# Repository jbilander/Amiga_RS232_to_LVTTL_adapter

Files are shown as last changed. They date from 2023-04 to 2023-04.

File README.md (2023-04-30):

# Amiga RS232 to LVTTL adapter

Amiga RS232 to LVTTL with 3.3V Power converted and taken directly from the DB25 serial port 12V-pin (pin 9)

***
VERIFIED WORKING!!!<br />
https://drive.google.com/file/d/105Ov4MyicygtOqv-1FFOkmMn0a-dk8-Z/view?usp=sharing
***

Revision 1A
<br />
<a href="images/RS232_to_LVTTL_rev1a_pic1.png">
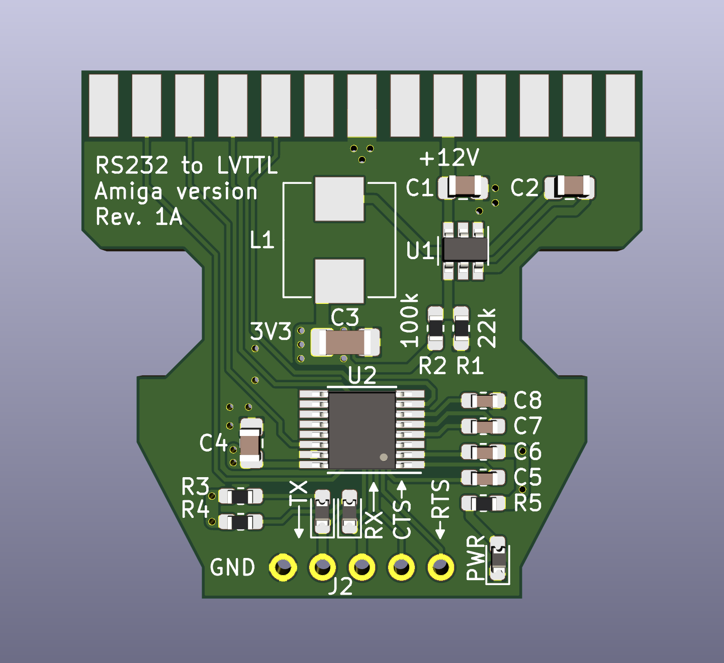
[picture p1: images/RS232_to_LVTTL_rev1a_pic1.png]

</a>
<a href="images/RS232_to_LVTTL_rev1a_pic2.png">
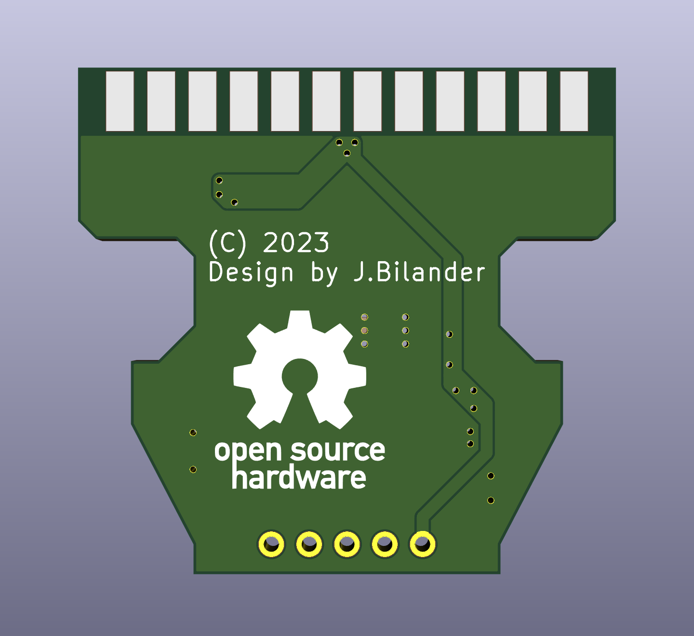
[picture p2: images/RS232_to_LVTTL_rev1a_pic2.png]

</a>
<br />
<a href="images/RS232_to_LVTTL_rev1a_pic3.png">
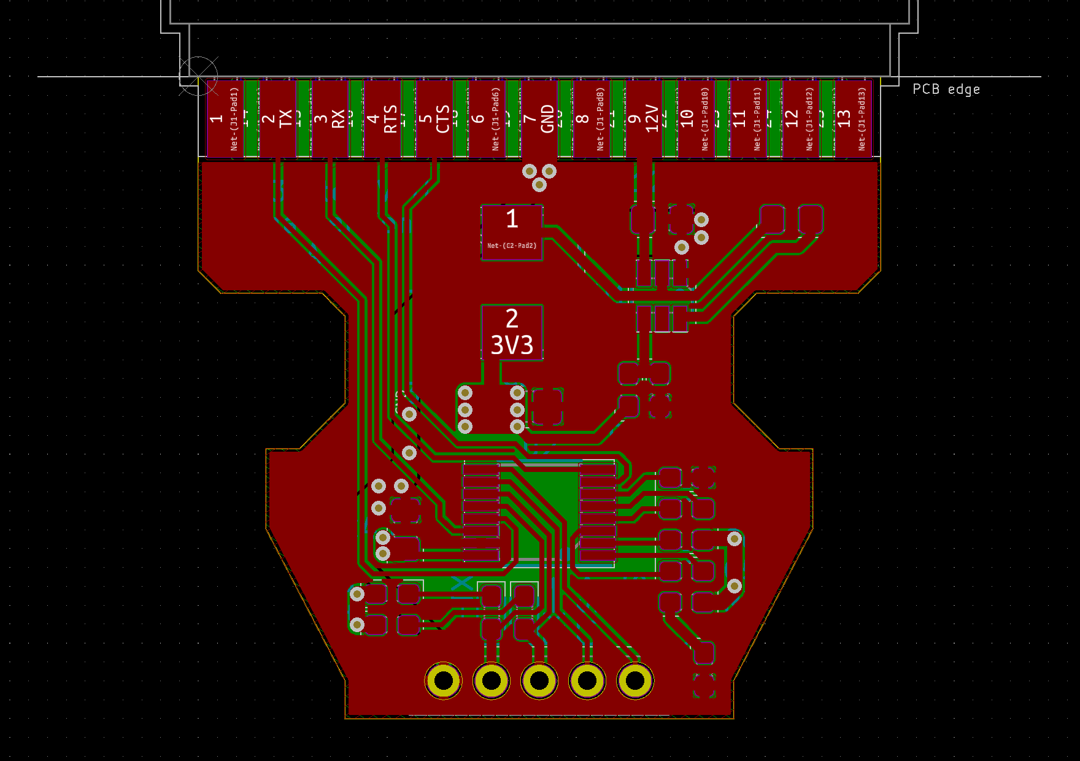
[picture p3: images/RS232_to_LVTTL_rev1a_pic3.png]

</a>
<br />
<a href="images/RS232_to_LVTTL_rev1a_pic4.jpg">
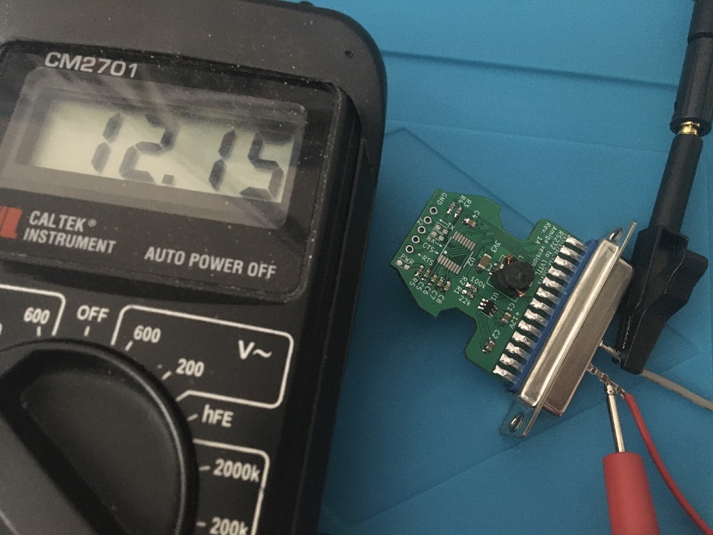
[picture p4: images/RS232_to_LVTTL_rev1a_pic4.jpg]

</a>
<a href="images/RS232_to_LVTTL_rev1a_pic5.jpg">
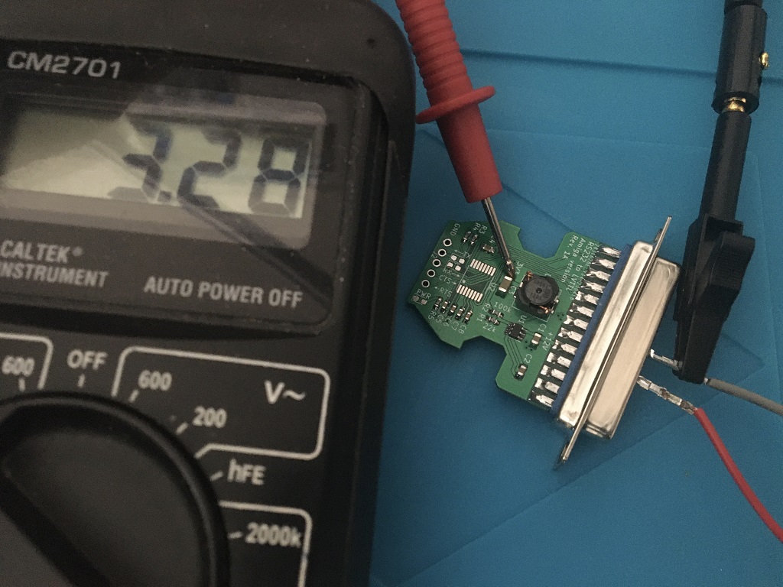
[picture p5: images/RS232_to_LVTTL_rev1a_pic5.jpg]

</a>
<br />
<a href="images/RS232_to_LVTTL_rev1a_pic6.jpg">
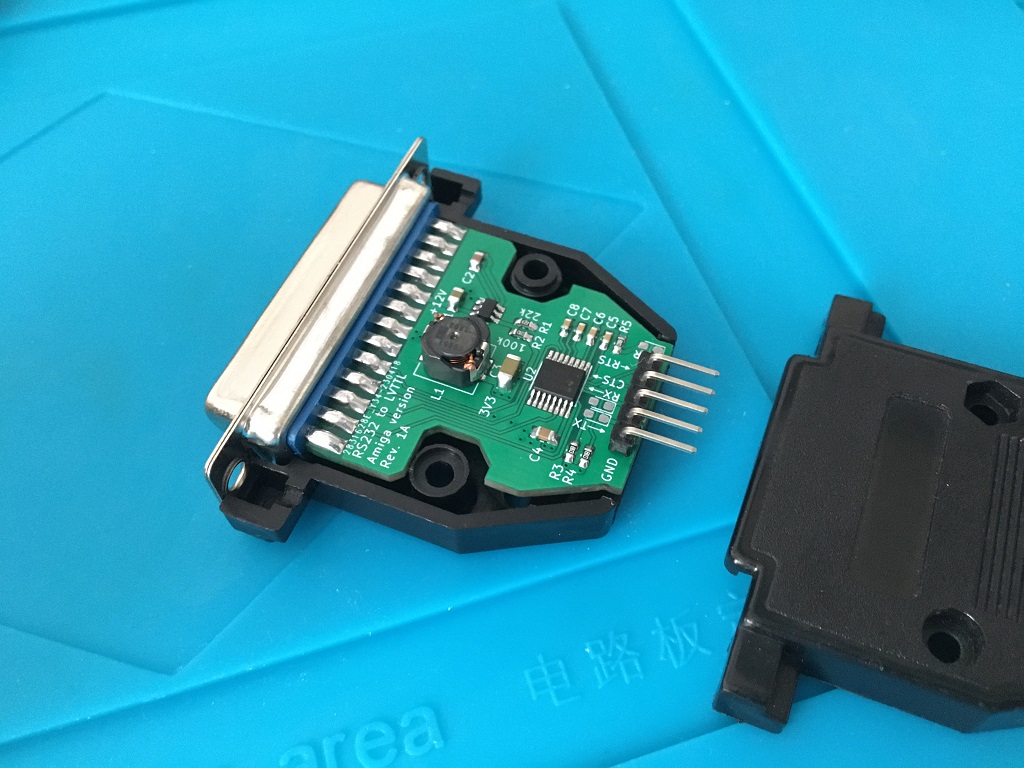
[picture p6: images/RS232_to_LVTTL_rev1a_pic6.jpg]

</a>

BOM Rev. 1A
---------
Designator  | Name/Value   | Package | Notes
-|-|-|-|
U1 | TPS54308 Step-down converter | SOT-23-6 | [TPS54308DDCR](https://www.mouser.com/ProductDetail/595-TPS54308DDCR)
U2 | MAX3232 RS-232 Interface IC 3-5.5V | TSSOP-16 | [MAX3232IPWR](https://www.mouser.com/ProductDetail/595-MAX3232IPWR)
L1 | CLF7045NIT-100M-D Power Inductor, 10 uH | 7 mm x 7 mm, height 4.5 mm | [CLF7045NIT](https://www.mouser.com/ProductDetail/810-CLF7045NIT100MD)
J1 | D-Sub DB25 Female connector | EdgeMount, serial port connector solder type | [D-Sub DB25F](https://www.aliexpress.com/item/32885764031.html)
J2 | 1x05 Right-Angle Single Row Male Pin Header | Type/Color: Reverse | [PinHeader](https://www.aliexpress.com/item/32892547934.html)
R1 | Feedback Resistor 22k Ω | 0603 | [RC0603FR-0722KL](https://www.mouser.com/ProductDetail/603-RC0603FR-0722KL)
R2 | Feedback Resistor 100k Ω | 0603 | [RC0603FR-07100KL](https://www.mouser.com/ProductDetail/603-RC0603FR-07100KL) 
R3-R5 | LED Resistor 1k Ω | 0603 | [RC0603FR-071KL](https://www.mouser.com/ProductDetail/603-RC0603FR-071KL)
C1 | Capacitor 10uF | 0805 | [TMK212BBJ106KG-T](https://www.mouser.com/ProductDetail/963-TMK212BBJ106KG-T)
C2,C4 | Capacitor 0.1uF = 100nF | 0805 |
C3 | Capacitor 47uF | 1206 | [EMK316BBJ476ML-T](https://www.mouser.com/ProductDetail/963-EMK316BBJ476ML-T)
C5-C8 | Capacitor 0.1uF = 100nF | 0603 | [CL10B104KO8NNWC](https://www.mouser.com/ProductDetail/187-CL10B104KO8NNWC)
D1-D3 | SMD LED | 0603 | [SMD LED 0603](https://www.aliexpress.com/item/1005003836509392.html)

***

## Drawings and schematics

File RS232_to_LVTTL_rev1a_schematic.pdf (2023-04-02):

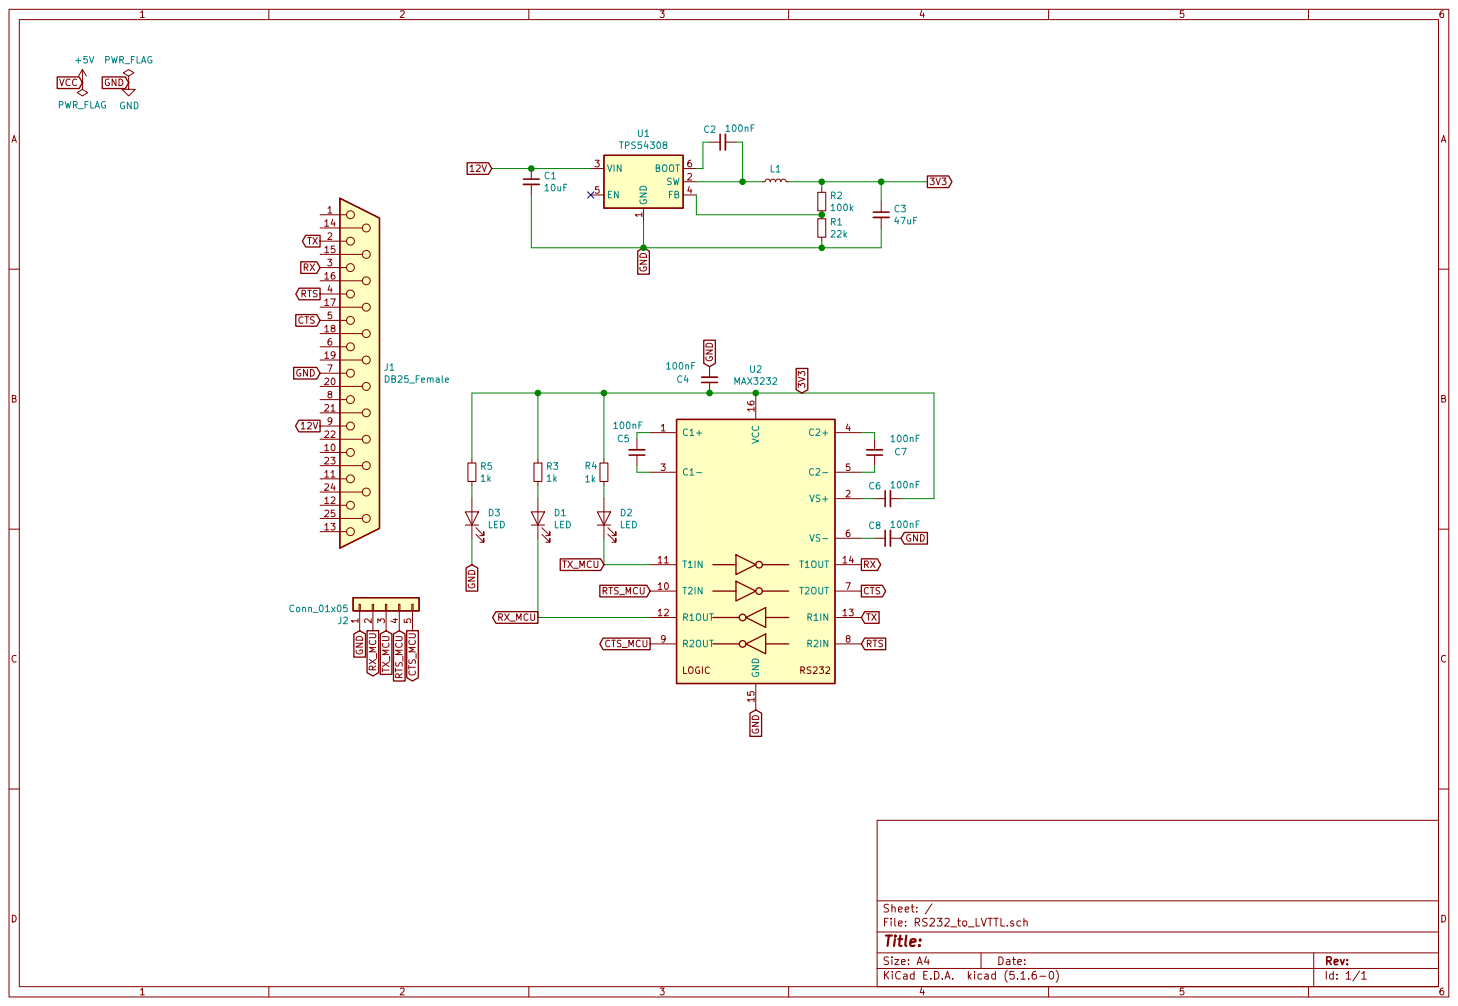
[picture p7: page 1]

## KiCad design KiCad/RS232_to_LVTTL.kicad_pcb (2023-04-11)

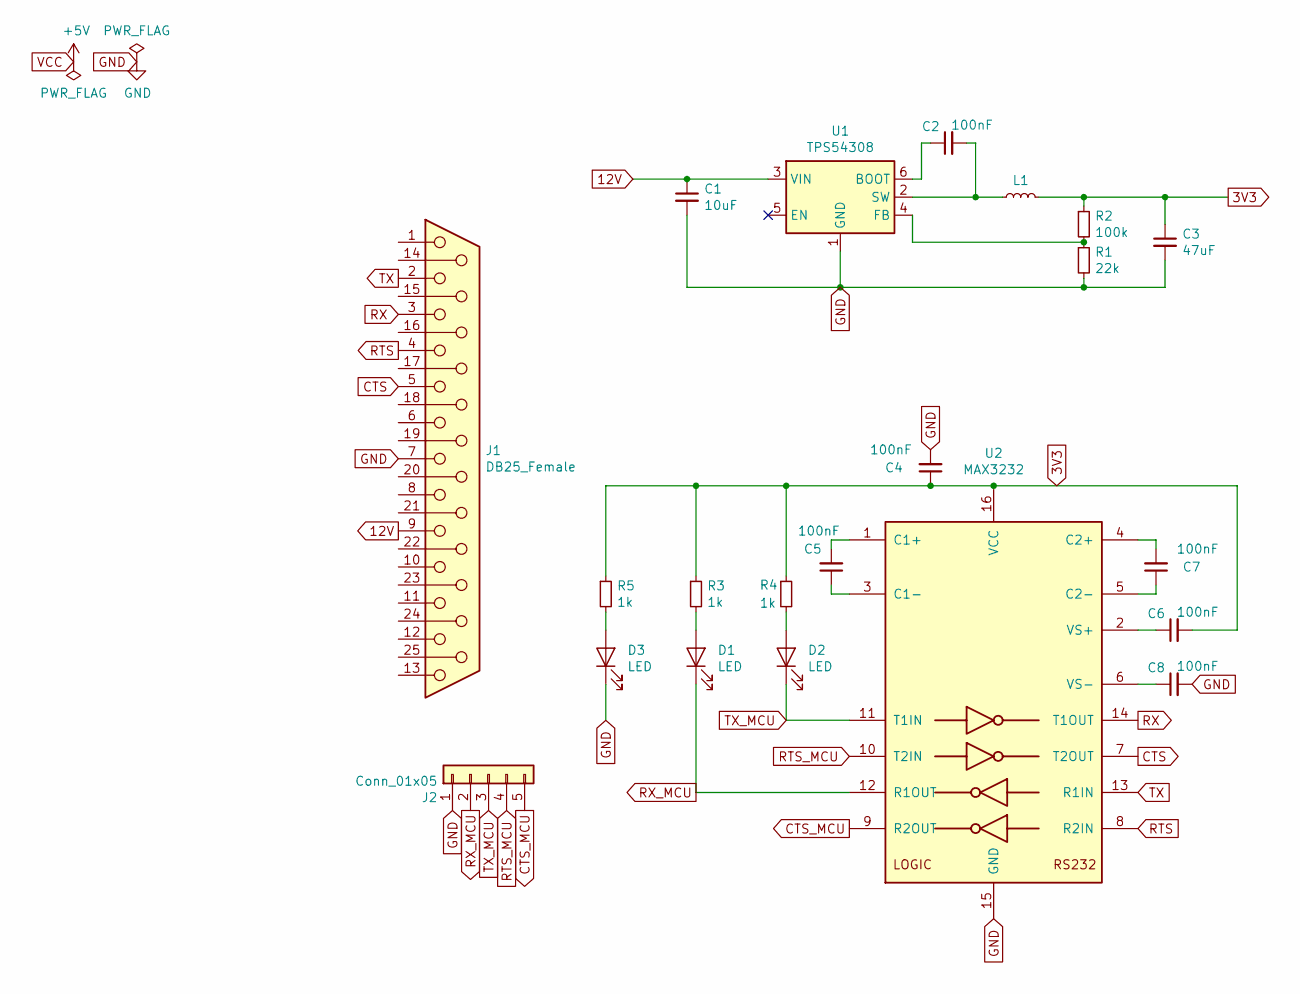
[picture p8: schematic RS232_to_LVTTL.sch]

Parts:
C1: 10uF; C_0805_2012Metric_Pad1.15x1.40mm_HandSolder
C2, C4: 100nF; C_0805_2012Metric_Pad1.15x1.40mm_HandSolder
C3: 47uF; C_1206_3216Metric_Pad1.42x1.75mm_HandSolder
C5, C6, C7, C8: 100nF; C_0603_1608Metric_Pad1.05x0.95mm_HandSolder
D1, D2, D3: LED; D_0603_1608Metric_Pad1.05x0.95mm_HandSolder
J1: DB25_Female; DSUB-25_Female_EdgeMount_P2.77mm
J2: Conn_01x05; PinHeader_1x05_P2.54mm_Vertical
L1: L_Small; L_Wuerth_HCM-7050
R1: 22k; R_0603_1608Metric_Pad1.05x0.95mm_HandSolder
R2: 100k; R_0603_1608Metric_Pad1.05x0.95mm_HandSolder
R3, R4, R5: 1k; R_0603_1608Metric_Pad1.05x0.95mm_HandSolder
U1: TPS54308; SOT-23-6
U2: MAX3232; TSSOP-16_4.4x5mm_P0.65mm

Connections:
3V3: C3.1, C4.1, C6.2, L1.2, R2.1, R3.1, R4.1, R5.1, U2.16 (VCC)
12V: C1.1, J1.9, U1.3 (VIN)
CTS: J1.5, U2.7 (T2OUT)
CTS_MCU: J2.5, U2.9 (R2OUT)
GND: C1.2, C3.2, C4.2, C8.2, D3.1 (K), J1.7, J2.1, R1.2, U1.1 (GND), U2.15 (GND)
unnamed: C2.1, U1.6 (BOOT)
unnamed: C2.2, L1.1, U1.2 (SW)
unnamed: C5.1, U2.3 (C1-)
unnamed: C5.2, U2.1 (C1+)
unnamed: C6.1, U2.2 (VS+)
unnamed: C7.1, U2.5 (C2-)
unnamed: C7.2, U2.4 (C2+)
unnamed: C8.1, U2.6 (VS-)
unnamed: D1.2 (A), R3.2
unnamed: D2.2 (A), R4.2
unnamed: D3.2 (A), R5.2
unnamed: R1.1, R2.2, U1.4 (FB)
RTS: J1.4, U2.8 (R2IN)
RTS_MCU: J2.4, U2.10 (T2IN)
RX: J1.3, U2.14 (T1OUT)
RX_MCU: D1.1 (K), J2.2, U2.12 (R1OUT)
TX: J1.2, U2.13 (R1IN)
TX_MCU: D2.1 (K), J2.3, U2.11 (T1IN)

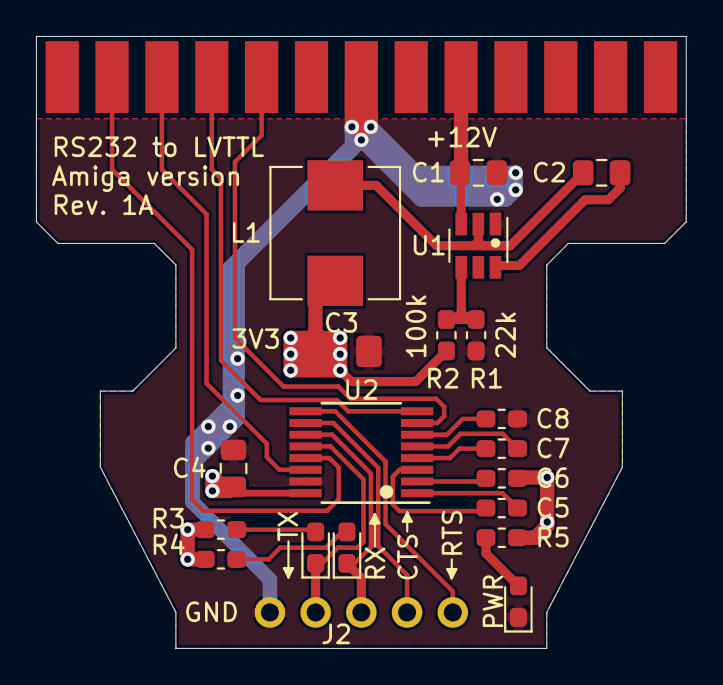
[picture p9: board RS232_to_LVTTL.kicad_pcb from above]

Board: 2 copper layers, 36.1 x 34.0 mm, 21 parts (0 on the bottom side), 23 nets.

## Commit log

2023-03-30 Added KiCAD-files
    [RS232_to_LVTTL.kicad_pcb, RS232_to_LVTTL.sch]
2023-03-31 Added power circuit convert 12V to 3.3V
    [RS232_to_LVTTL.kicad_pcb, RS232_to_LVTTL.sch]
2023-03-31 Added MAX3232 chip
    [RS232_to_LVTTL.kicad_pcb, RS232_to_LVTTL.sch]
2023-03-31 Added 5-pin header for TX,RX,RTS,CTS,GND
    [RS232_to_LVTTL.kicad_pcb, RS232_to_LVTTL.sch]
2023-03-31 Fixed positioning of 5-pin header
    [RS232_to_LVTTL.kicad_pcb, RS232_to_LVTTL.sch]
2023-04-01 routing and placing of components
    [RS232_to_LVTTL.kicad_pcb, RS232_to_LVTTL.sch]
2023-04-01 Added a PWR LED and some final routing and silkscreen fixes
    [RS232_to_LVTTL.kicad_pcb, RS232_to_LVTTL.sch]
2023-04-02 some small routing and silkscreen fixes
    [RS232_to_LVTTL.kicad_pcb, RS232_to_LVTTL.sch]
2023-04-02 small fix in schematic
    [RS232_to_LVTTL.sch]
2023-04-02 Added schematic pdf
2023-04-11 Moved the Inductor a little to the right to get further away from the signal traces
    [RS232_to_LVTTL.kicad_pcb]
2023-04-17 moved schematic pdf up one level

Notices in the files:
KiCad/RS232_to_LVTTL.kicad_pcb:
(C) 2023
